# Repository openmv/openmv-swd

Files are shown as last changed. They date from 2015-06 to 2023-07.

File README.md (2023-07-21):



# openmv-swd
Serial Wire Debugger Programmer

The Serial Wire Debugger (SWD) Programmer can load firmware on up to five STM32F427/STM32F765/STM32H743 microcontrollers at the same time. The SWD Programmer is powered by the Propeller Chip. All eight cores of the Propeller Chip are used by the SWD Programmer firmware. Each SWD programming thread is run in a separate core. A master core controls the five SWD programming cores. Finally, one core provides SD card services while another core handles button debouncing and LED PWM.

If you're interested in practical code demonstrating how to load the firmware on an ST32F427/STM32F765/STM32H743 microcontroller, or generally, any ST Cortex-M4/Cortex-M7 device checkout the [SWD Code](http://github.com/openmv/openmv-swd/blob/master/module/V2/src/SWD.spin).

# openmv-swd application

* Install 7-Zip and add it to PATH.
* Install Python 2.7 and add it to PATH.
* Install Qt (to the default location).
* Install The Qt Installer Framework (to the default location).

In `/`, build the application (using the standard bare terminal):

     make.py

You'll find the installer in `module/build`.

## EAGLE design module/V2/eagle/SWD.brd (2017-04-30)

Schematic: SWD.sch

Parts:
3.3V_1,1, 3.3V_1,2, 3.3V_1,3, 3.3V_1,4, 3.3V_2,1, 3.3V_2,2, 3.3V_2,3, 3.3V_2,4, 3.3V_3,1, 3.3V_3,2, 3.3V_3,3, 3.3V_3,4, 3.3V_4,1, 3.3V_4,2, 3.3V_4,3, 3.3V_4,4, 3.3V_5,1, 3.3V_5,2, 3.3V_5,3, 3.3V_5,4: POGO_PIN_0908-4-15-20-75-14-11-0; 0908-4-15-20-75-14-11-0
C1, C2, C3, C4, C5, C6, C7, C10, C12, C13, C15, C16, C17, C18, C19, C20, C21, C22, C23, C24, C25, C27, C28, C29, C30, C31, C32, C33, C34, C35, C61, C62: 0.1uF; C0603
C8, C9: 47pF; C0603
C11, C14: 1uF; C0603
C26: 0.1uF\; C0603
C36, C37, C38, C39: 100uF; CP6.3MM
D1, D2, D3: MF-LED-0805-RED; LED0805
D4: SMBJ5.0CA; SMBJ
FRAME1: MF_FRAMEDEFAULT; MF_FRAME_DEFAULT
GND_1,1, GND_1,2, GND_1,3, GND_1,4, GND_2,1, GND_2,2, GND_2,3, GND_2,4, GND_3,1, GND_3,2, GND_3,3, GND_3,4, GND_4,1, GND_4,2, GND_4,3, GND_4,4, GND_5,1, GND_5,2, GND_5,3, GND_5,4: POGO_PIN_0908-4-15-20-75-14-11-0; 0908-4-15-20-75-14-11-0
J1: USB_TYPE-C_105450-0101; 105450-0101
J2: KLDX-0202-A; DC_PWR_JACK
L1, L2: MI0603K300R-10; L0603
R1, R2, R3, R4, R5, R6, R7, R8, R9, R14, R30, R31, R32, R33: 10K; R0603
R10: 5.1K; R0603
R11, R12: 27; R0603
R13: 4.7K; R0603
R15, R16, R17, R18, R19, R20, R21, R22, R23, R24, R25, R26, R27, R28, R29: 100; R0603
R34, R35, R36: 360; R0603
SD1: MF-MICROSD
SW1, SW2: MF-SW-TACT-6MM; TACT6MM
SWD_CLK_1,1, SWD_CLK_1,2, SWD_CLK_1,3, SWD_CLK_1,4, SWD_CLK_2,1, SWD_CLK_2,2, SWD_CLK_2,3, SWD_CLK_2,4, SWD_CLK_3,1, SWD_CLK_3,2, SWD_CLK_3,3, SWD_CLK_3,4, SWD_CLK_4,1, SWD_CLK_4,2, SWD_CLK_4,3, SWD_CLK_4,4, SWD_CLK_5,1, SWD_CLK_5,2, SWD_CLK_5,3, SWD_CLK_5,4: POGO_PIN_0908-4-15-20-75-14-11-0; 0908-4-15-20-75-14-11-0
SWD_DAT_1,1, SWD_DAT_1,2, SWD_DAT_1,3, SWD_DAT_1,4, SWD_DAT_2,1, SWD_DAT_2,2, SWD_DAT_2,3, SWD_DAT_2,4, SWD_DAT_3,1, SWD_DAT_3,2, SWD_DAT_3,3, SWD_DAT_3,4, SWD_DAT_4,1, SWD_DAT_4,2, SWD_DAT_4,3, SWD_DAT_4,4, SWD_DAT_5,1, SWD_DAT_5,2, SWD_DAT_5,3, SWD_DAT_5,4: POGO_PIN_0908-4-15-20-75-14-11-0; 0908-4-15-20-75-14-11-0
SWD_RST_1,1, SWD_RST_1,2, SWD_RST_1,3, SWD_RST_1,4, SWD_RST_2,1, SWD_RST_2,2, SWD_RST_2,3, SWD_RST_2,4, SWD_RST_3,1, SWD_RST_3,2, SWD_RST_3,3, SWD_RST_3,4, SWD_RST_4,1, SWD_RST_4,2, SWD_RST_4,3, SWD_RST_4,4, SWD_RST_5,1, SWD_RST_5,2, SWD_RST_5,3, SWD_RST_5,4: POGO_PIN_0908-4-15-20-75-14-11-0; 0908-4-15-20-75-14-11-0
U1: P8X32A-Q44; LQFP44
U2: CAT24C512WI-GT3; SOIC-8_W
U3: FT230XQ-R; FT230X_QFN-16
U4, U5, U6, U7, U8, U9, U10, U11, U12, U13, U14, U15, U16, U17, U18, U19, U20, U21, U22, U23: SN74LV4066APWR; SN74LV4066A_TSSOP-14
U24, U25, U26, U27: SSM6J507NU,LF; SSM6J507NU
U$59: MF_LOGOLOGO_TEXT; MF_LOGO_TEXT
UNIT1, UNIT2, UNIT3, UNIT4, UNIT5, UNIT6, UNIT7, UNIT8, UNIT9, UNIT10, UNIT11, UNIT12, UNIT13, UNIT14, UNIT15, UNIT16, UNIT17, UNIT18, UNIT19, UNIT20: OPENMV3
X1: ABMM-6.000MHZ-B2-T; 7MMX5MM

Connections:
3.3V: C1.P$1, C2.P$1, C3.P$1, C4.P$1, C5.P$1, C6.P$1, C7.P$1, C13.P$1, C14.P$1, C16.P$2, C17.P$2, C18.P$2, C19.P$2, C20.P$2, C21.P$2, C22.P$2, C23.P$2, C24.P$2, C25.P$2, C26.P$2, C27.P$2, C28.P$2, C29.P$2, C30.P$2, C31.P$2, C32.P$2, C33.P$2, C34.P$2, C35.P$2, C36.P$1, C37.P$1, C38.P$1, C39.P$1, C61.P$1, C62.P$1, D1.ANODE, D2.ANODE, D3.ANODE, D4.CATH (CATHODE), J2.PIN, R1.P$1, R2.P$1, R3.P$1, R4.P$1, R5.P$1, R6.P$1, R7.P$1, R8.P$1, R9.P$1, R30.P$1, R31.P$1, R32.P$1, R33.P$1, SD1.PIN4 (3.3V), U1.8 (VDD), U1.18 (VDD), U1.30 (VDD), U1.40 (VDD), U2.8 (VCC), U3.1 (VCCIO), U3.9 (RESET#), U3.10 (VCC), U4.P$14 (VCC), U5.P$14 (VCC), U6.P$14 (VCC), U7.P$14 (VCC), U8.P$14 (VCC), U9.P$14 (VCC), U10.P$14 (VCC), U11.P$14 (VCC), U12.P$14 (VCC), U13.P$14 (VCC), U14.P$14 (VCC), U15.P$14 (VCC), U16.P$14 (VCC), U17.P$14 (VCC), U18.P$14 (VCC), U19.P$14 (VCC), U20.P$14 (VCC), U21.P$14 (VCC), U22.P$14 (VCC), U23.P$14 (VCC), U24.P$1 (DRAIN), U24.P$2 (DRAIN), U24.P$5 (DRAIN), U24.P$6 (DRAIN), U24.P$8 (DRAIN), U25.P$1 (DRAIN), U25.P$2 (DRAIN), U25.P$5 (DRAIN), U25.P$6 (DRAIN), U25.P$8 (DRAIN), U26.P$1 (DRAIN), U26.P$2 (DRAIN), U26.P$5 (DRAIN), U26.P$6 (DRAIN), U26.P$8 (DRAIN), U27.P$1 (DRAIN), U27.P$2 (DRAIN), U27.P$5 (DRAIN), U27.P$6 (DRAIN), U27.P$8 (DRAIN)
3.3V_R1: 3.3V_1,1.P$1, 3.3V_2,1.P$1, 3.3V_3,1.P$1, 3.3V_4,1.P$1, 3.3V_5,1.P$1, U24.P$4 (SOURCE), U24.P$7 (SOURCE)
3.3V_R2: 3.3V_1,2.P$1, 3.3V_2,2.P$1, 3.3V_3,2.P$1, 3.3V_4,2.P$1, 3.3V_5,2.P$1, U25.P$4 (SOURCE), U25.P$7 (SOURCE)
3.3V_R3: 3.3V_1,3.P$1, 3.3V_2,3.P$1, 3.3V_3,3.P$1, 3.3V_4,3.P$1, 3.3V_5,3.P$1, U26.P$4 (SOURCE), U26.P$7 (SOURCE)
3.3V_R4: 3.3V_1,4.P$1, 3.3V_2,4.P$1, 3.3V_3,4.P$1, 3.3V_4,4.P$1, 3.3V_5,4.P$1, U27.P$4 (SOURCE), U27.P$7 (SOURCE)
3V3OUT: C12.P$1, U3.8 (3V3OUT)
!RTS: C15.P$1, U3.16 (RTS#)
CC1: J1.A5 (CC1), R10.P$1
CTRL_ROW_1: U1.44 (P3), U4.P$5 (CNTRL), U4.P$6 (CNTRL), U4.P$13 (CNTRL), U8.P$5 (CNTRL), U8.P$6 (CNTRL), U8.P$13 (CNTRL), U12.P$5 (CNTRL), U12.P$6 (CNTRL), U12.P$13 (CNTRL), U16.P$5 (CNTRL), U16.P$6 (CNTRL), U16.P$13 (CNTRL), U20.P$5 (CNTRL), U20.P$6 (CNTRL), U20.P$13 (CNTRL)
CTRL_ROW_2: U1.43 (P2), U5.P$5 (CNTRL), U5.P$6 (CNTRL), U5.P$13 (CNTRL), U9.P$5 (CNTRL), U9.P$6 (CNTRL), U9.P$13 (CNTRL), U13.P$5 (CNTRL), U13.P$6 (CNTRL), U13.P$13 (CNTRL), U17.P$5 (CNTRL), U17.P$6 (CNTRL), U17.P$13 (CNTRL), U21.P$5 (CNTRL), U21.P$6 (CNTRL), U21.P$13 (CNTRL)
CTRL_ROW_3: U1.42 (P1), U6.P$5 (CNTRL), U6.P$6 (CNTRL), U6.P$13 (CNTRL), U10.P$5 (CNTRL), U10.P$6 (CNTRL), U10.P$13 (CNTRL), U14.P$5 (CNTRL), U14.P$6 (CNTRL), U14.P$13 (CNTRL), U18.P$5 (CNTRL), U18.P$6 (CNTRL), U18.P$13 (CNTRL), U22.P$5 (CNTRL), U22.P$6 (CNTRL), U22.P$13 (CNTRL)
CTRL_ROW_4: U1.41 (P0), U7.P$5 (CNTRL), U7.P$6 (CNTRL), U7.P$13 (CNTRL), U11.P$5 (CNTRL), U11.P$6 (CNTRL), U11.P$13 (CNTRL), U15.P$5 (CNTRL), U15.P$6 (CNTRL), U15.P$13 (CNTRL), U19.P$5 (CNTRL), U19.P$6 (CNTRL), U19.P$13 (CNTRL), U23.P$5 (CNTRL), U23.P$6 (CNTRL), U23.P$13 (CNTRL)
D+: C8.P$1, J1.A6 (D+), J1.B6 (D+), R11.P$1
D-: C9.P$1, J1.A7 (D-), J1.B7 (D-), R12.P$1
GND: C1.P$2, C2.P$2, C3.P$2, C4.P$2, C5.P$2, C6.P$2, C7.P$2, C8.P$2, C9.P$2, C10.P$2, C11.P$2, C12.P$2, C13.P$2, C14.P$2, C16.P$1, C17.P$1, C18.P$1, C19.P$1, C20.P$1, C21.P$1, C22.P$1, C23.P$1, C24.P$1, C25.P$1, C26.P$1, C27.P$1, C28.P$1, C29.P$1, C30.P$1, C31.P$1, C32.P$1, C33.P$1, C34.P$1, C35.P$1, C36.P$2, C37.P$2, C38.P$2, C39.P$2, C61.P$2, C62.P$2, D4.ANODE, GND_1,1.P$1, GND_1,2.P$1, GND_1,3.P$1, GND_1,4.P$1, GND_2,1.P$1, GND_2,2.P$1, GND_2,3.P$1, GND_2,4.P$1, GND_3,1.P$1, GND_3,2.P$1, GND_3,3.P$1, GND_3,4.P$1, GND_4,1.P$1, GND_4,2.P$1, GND_4,3.P$1, GND_4,4.P$1, GND_5,1.P$1, GND_5,2.P$1, GND_5,3.P$1, GND_5,4.P$1, J1.A1 (GND), J1.A12 (GND), J1.B1 (GND), J1.B12 (GND), J2.SLEEVE1 (SLEEVE), J2.SLEEVE2 (SLEEVE_SHUNT), L2.P$2, R10.P$2, R14.P$1, R35.P$2, SD1.G0 (GND), SD1.G1 (GND), SD1.PIN6 (GND), SW1.P$3, U1.5 (VSS), U1.6 (BOE'), U1.17 (VSS), U1.27 (VSS), U1.39 (VSS), U2.1 (A0), U2.2 (A1), U2.3 (A2), U2.4 (GND), U2.7 (WP), U3.3 (GND), U3.13 (GND), U3.PAD (GND), U4.P$7 (GND), U5.P$7 (GND), U6.P$7 (GND), U7.P$7 (GND), U8.P$7 (GND), U9.P$7 (GND), U10.P$7 (GND), U11.P$7 (GND), U12.P$7 (GND), U13.P$7 (GND), U14.P$7 (GND), U15.P$7 (GND), U16.P$7 (GND), U17.P$7 (GND), U18.P$7 (GND), U19.P$7 (GND), U20.P$7 (GND), U21.P$7 (GND), U22.P$7 (GND), U23.P$7 (GND), X1.P$2 (GND), X1.P$4 (GND)
I2C_SCL: R9.P$2, U1.35 (P28), U2.6 (SCL)
I2C_SDA: R8.P$2, U1.36 (P29), U2.5 (SDA)
IRQ: R2.P$2, SD1.PIN8 (IRQ)
LED_HB: R36.P$2, U1.26 (P23)
unnamed: R16.P$1, U4.P$4 (A), U5.P$4 (A), U6.P$4 (A), U7.P$4 (A)
unnamed: R18.P$1, U8.P$1 (A), U9.P$1 (A), U10.P$1 (A), U11.P$1 (A)
unnamed: R15.P$1, U4.P$1 (A), U5.P$1 (A), U6.P$1 (A), U7.P$1 (A)
unnamed: R20.P$1, U8.P$8 (A), U9.P$8 (A), U10.P$8 (A), U11.P$8 (A)
unnamed: R19.P$1, U8.P$4 (A), U9.P$4 (A), U10.P$4 (A), U11.P$4 (A)
unnamed: R21.P$1, U12.P$1 (A), U13.P$1 (A), U14.P$1 (A), U15.P$1 (A)
unnamed: R23.P$1, U12.P$8 (A), U13.P$8 (A), U14.P$8 (A), U15.P$8 (A)
unnamed: R17.P$1, U4.P$8 (A), U5.P$8 (A), U6.P$8 (A), U7.P$8 (A)
unnamed: R22.P$1, U12.P$4 (A), U13.P$4 (A), U14.P$4 (A), U15.P$4 (A)
unnamed: R24.P$1, U16.P$1 (A), U17.P$1 (A), U18.P$1 (A), U19.P$1 (A)
unnamed: R26.P$1, U16.P$8 (A), U17.P$8 (A), U18.P$8 (A), U19.P$8 (A)
unnamed: R25.P$1, U16.P$4 (A), U17.P$4 (A), U18.P$4 (A), U19.P$4 (A)
unnamed: R27.P$1, U20.P$1 (A), U21.P$1 (A), U22.P$1 (A), U23.P$1 (A)
unnamed: R29.P$1, U20.P$8 (A), U21.P$8 (A), U22.P$8 (A), U23.P$8 (A)
unnamed: R28.P$1, U20.P$4 (A), U21.P$4 (A), U22.P$4 (A), U23.P$4 (A)
unnamed: D3.CATHODE, R36.P$1
unnamed: D2.CATHODE, R35.P$1
unnamed: C15.P$2, SW2.P$1
unnamed: D1.CATHODE, R34.P$1
PWR_1: R30.P$2, U1.22 (P19), U24.P$3 (GATE)
PWR_2: R31.P$2, U1.23 (P20), U25.P$3 (GATE)
PWR_3: R32.P$2, U1.24 (P21), U26.P$3 (GATE)
PWR_4: R33.P$2, U1.25 (P22), U27.P$3 (GATE)
RES: R1.P$2, SW1.P$2, SW2.P$4, U1.7 (RES')
RW: R7.P$2, SD1.PIN1 (RW)
RX: U1.37 (P30), U3.2 (RXD)
SD_CLK: R4.P$2, SD1.PIN5 (SCLK), U1.32 (P25)
SD_CS: R6.P$2, SD1.PIN2 (CS), U1.34 (P27)
SD_DI: R5.P$2, SD1.PIN3 (DI), U1.33 (P26)
SD_DO: R3.P$2, SD1.PIN7 (D0), U1.31 (P24)
SHLD: J1.S_T1 (SHLD), J1.S_T2 (SHLD), J1.S_T3 (SHLD), J1.S_T4 (SHLD), L2.P$1
SWD_CLK_1: R15.P$2, U1.1 (P4)
SWD_CLK_1,1: SWD_CLK_1,1.P$1, U4.P$2 (B)
SWD_CLK_1,2: SWD_CLK_1,2.P$1, U5.P$2 (B)
SWD_CLK_1,3: SWD_CLK_1,3.P$1, U6.P$2 (B)
SWD_CLK_1,4: SWD_CLK_1,4.P$1, U7.P$2 (B)
SWD_CLK_2: R18.P$2, U1.4 (P7)
SWD_CLK_2,1: SWD_CLK_2,1.P$1, U8.P$2 (B)
SWD_CLK_2,2: SWD_CLK_2,2.P$1, U9.P$2 (B)
SWD_CLK_2,3: SWD_CLK_2,3.P$1, U10.P$2 (B)
SWD_CLK_2,4: SWD_CLK_2,4.P$1, U11.P$2 (B)
SWD_CLK_3: R21.P$2, U1.11 (P10)
SWD_CLK_3,1: SWD_CLK_3,1.P$1, U12.P$2 (B)
SWD_CLK_3,2: SWD_CLK_3,2.P$1, U13.P$2 (B)
SWD_CLK_3,3: SWD_CLK_3,3.P$1, U14.P$2 (B)
SWD_CLK_3,4: SWD_CLK_3,4.P$1, U15.P$2 (B)
SWD_CLK_4: R24.P$2, U1.14 (P13)
SWD_CLK_4,1: SWD_CLK_4,1.P$1, U16.P$2 (B)
SWD_CLK_4,2: SWD_CLK_4,2.P$1, U17.P$2 (B)
SWD_CLK_4,3: SWD_CLK_4,3.P$1, U18.P$2 (B)
SWD_CLK_4,4: SWD_CLK_4,4.P$1, U19.P$2 (B)
SWD_CLK_5: R27.P$2, U1.19 (P16)
SWD_CLK_5,1: SWD_CLK_5,1.P$1, U20.P$2 (B)
SWD_CLK_5,2: SWD_CLK_5,2.P$1, U21.P$2 (B)
SWD_CLK_5,3: SWD_CLK_5,3.P$1, U22.P$2 (B)
SWD_CLK_5,4: SWD_CLK_5,4.P$1, U23.P$2 (B)
SWD_DAT_1: R16.P$2, U1.2 (P5)
SWD_DAT_1,1: SWD_DAT_1,1.P$1, U4.P$3 (B)
SWD_DAT_1,2: SWD_DAT_1,2.P$1, U5.P$3 (B)
SWD_DAT_1,3: SWD_DAT_1,3.P$1, U6.P$3 (B)
SWD_DAT_1,4: SWD_DAT_1,4.P$1, U7.P$3 (B)
SWD_DAT_2: R19.P$2, U1.9 (P8)
SWD_DAT_2,1: SWD_DAT_2,1.P$1, U8.P$3 (B)
SWD_DAT_2,2: SWD_DAT_2,2.P$1, U9.P$3 (B)
SWD_DAT_2,3: SWD_DAT_2,3.P$1, U10.P$3 (B)
SWD_DAT_2,4: SWD_DAT_2,4.P$1, U11.P$3 (B)
SWD_DAT_3: R22.P$2, U1.12 (P11)
SWD_DAT_3,1: SWD_DAT_3,1.P$1, U12.P$3 (B)
SWD_DAT_3,2: SWD_DAT_3,2.P$1, U13.P$3 (B)
SWD_DAT_3,3: SWD_DAT_3,3.P$1, U14.P$3 (B)
SWD_DAT_3,4: SWD_DAT_3,4.P$1, U15.P$3 (B)
SWD_DAT_4: R25.P$2, U1.15 (P14)
SWD_DAT_4,1: SWD_DAT_4,1.P$1, U16.P$3 (B)
SWD_DAT_4,2: SWD_DAT_4,2.P$1, U17.P$3 (B)
SWD_DAT_4,3: SWD_DAT_4,3.P$1, U18.P$3 (B)
SWD_DAT_4,4: SWD_DAT_4,4.P$1, U19.P$3 (B)
SWD_DAT_5: R28.P$2, U1.20 (P17)
SWD_DAT_5,1: SWD_DAT_5,1.P$1, U20.P$3 (B)
SWD_DAT_5,2: SWD_DAT_5,2.P$1, U21.P$3 (B)
SWD_DAT_5,3: SWD_DAT_5,3.P$1, U22.P$3 (B)
SWD_DAT_5,4: SWD_DAT_5,4.P$1, U23.P$3 (B)
SWD_RST_1: R17.P$2, U1.3 (P6)
SWD_RST_1,1: SWD_RST_1,1.P$1, U4.P$9 (B)
SWD_RST_1,2: SWD_RST_1,2.P$1, U5.P$9 (B)
SWD_RST_1,3: SWD_RST_1,3.P$1, U6.P$9 (B)
SWD_RST_1,4: SWD_RST_1,4.P$1, U7.P$9 (B)
SWD_RST_2: R20.P$2, U1.10 (P9)
SWD_RST_2,1: SWD_RST_2,1.P$1, U8.P$9 (B)
SWD_RST_2,2: SWD_RST_2,2.P$1, U9.P$9 (B)
SWD_RST_2,3: SWD_RST_2,3.P$1, U10.P$9 (B)
SWD_RST_2,4: SWD_RST_2,4.P$1, U11.P$9 (B)
SWD_RST_3: R23.P$2, U1.13 (P12)
SWD_RST_3,1: SWD_RST_3,1.P$1, U12.P$9 (B)
SWD_RST_3,2: SWD_RST_3,2.P$1, U13.P$9 (B)
SWD_RST_3,3: SWD_RST_3,3.P$1, U14.P$9 (B)
SWD_RST_3,4: SWD_RST_3,4.P$1, U15.P$9 (B)
SWD_RST_4: R26.P$2, U1.16 (P15)
SWD_RST_4,1: SWD_RST_4,1.P$1, U16.P$9 (B)
SWD_RST_4,2: SWD_RST_4,2.P$1, U17.P$9 (B)
SWD_RST_4,3: SWD_RST_4,3.P$1, U18.P$9 (B)
SWD_RST_4,4: SWD_RST_4,4.P$1, U19.P$9 (B)
SWD_RST_5: R29.P$2, U1.21 (P18)
SWD_RST_5,1: SWD_RST_5,1.P$1, U20.P$9 (B)
SWD_RST_5,2: SWD_RST_5,2.P$1, U21.P$9 (B)
SWD_RST_5,3: SWD_RST_5,3.P$1, U22.P$9 (B)
SWD_RST_5,4: SWD_RST_5,4.P$1, U23.P$9 (B)
TX: U1.38 (P31), U3.15 (TXD)
TXRX_LED: R34.P$2, U3.5 (CBUS2)
USBDM: R12.P$2, U3.7 (USBDM)
USBDP: R11.P$2, U3.6 (USBDP)
VBUS_SENSE: R13.P$1, R14.P$2, U3.12 (CBUS0)
V_USB: J1.A4 (VBUS), J1.A9 (VBUS), J1.B4 (VBUS), J1.B9 (VBUS), L1.P$1
V_USB_SENSE: C10.P$1, C11.P$1, L1.P$2, R13.P$2
X0: U1.29 (X0), X1.P$3 (X1)
X1: U1.28 (X1), X1.P$1 (X0)

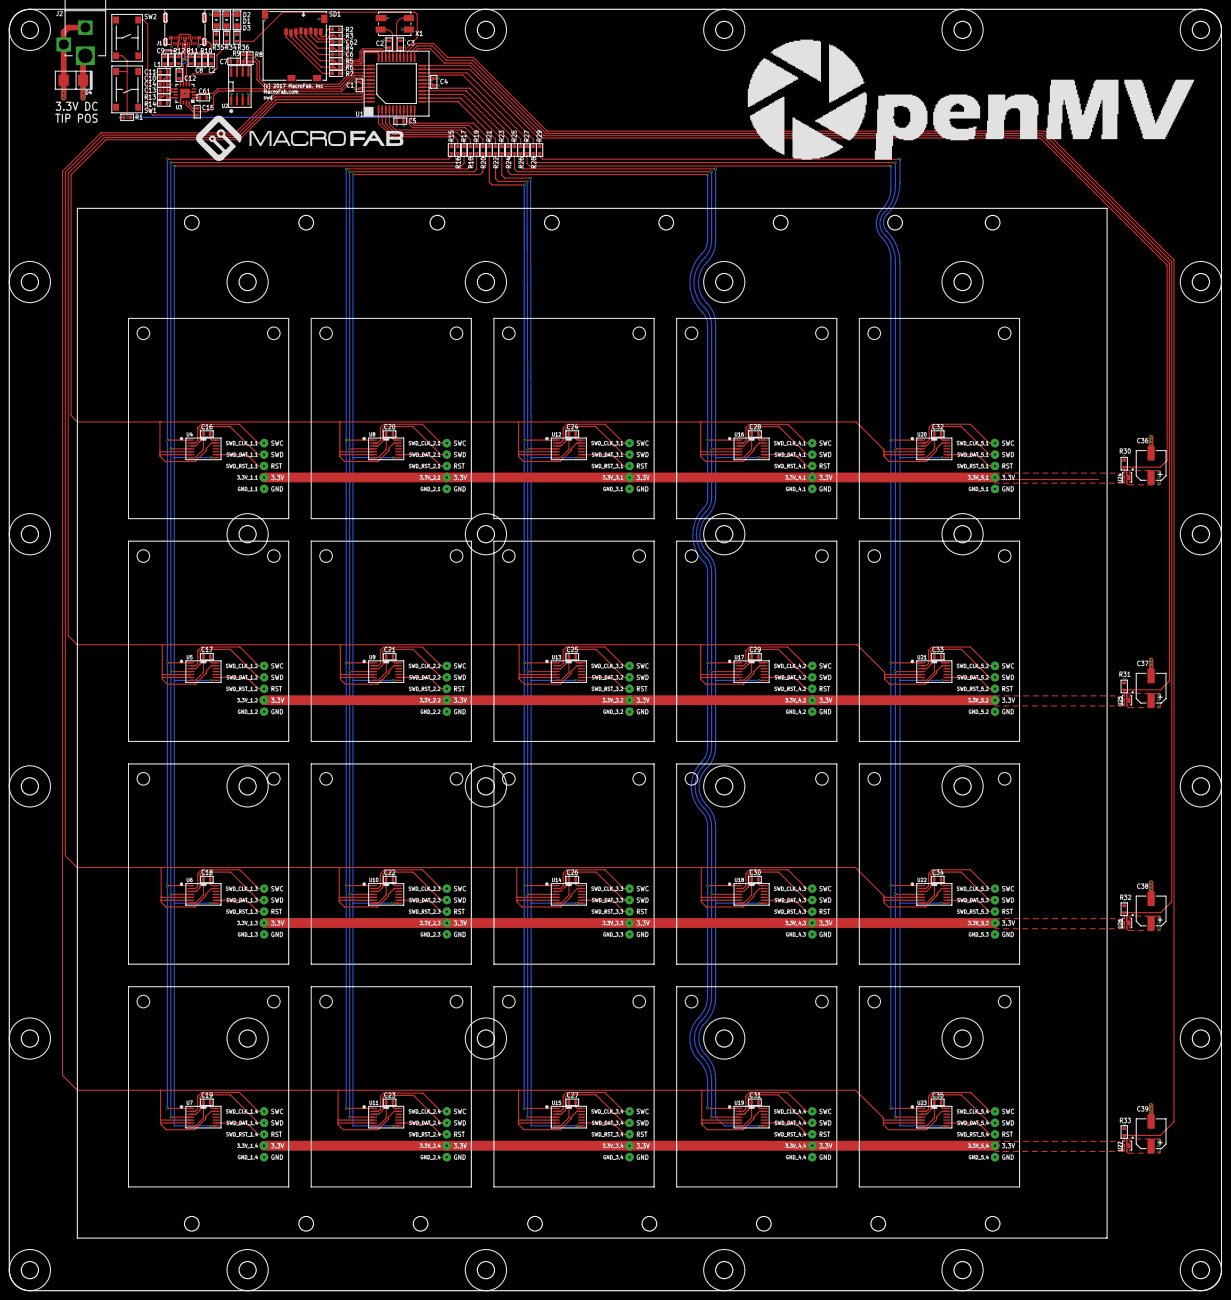
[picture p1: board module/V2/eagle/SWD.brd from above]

Board: 4 copper layers, 269.1 x 284.5 mm, 273 parts (0 on the bottom side), 134 nets.

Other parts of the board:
U$24, U$25, U$26, U$27, U$28, U$29, U$30, U$31, U$32, U$33, U$34, U$35, U$36, U$37, U$38, U$39, U$40, U$41, U$42, U$43, U$44, U$45, U$46, U$47, U$48, U$49, U$50, U$51, U$52, U$53, U$54, U$55, U$56, U$57, U$58: MOUNT_HOLE_150MIL

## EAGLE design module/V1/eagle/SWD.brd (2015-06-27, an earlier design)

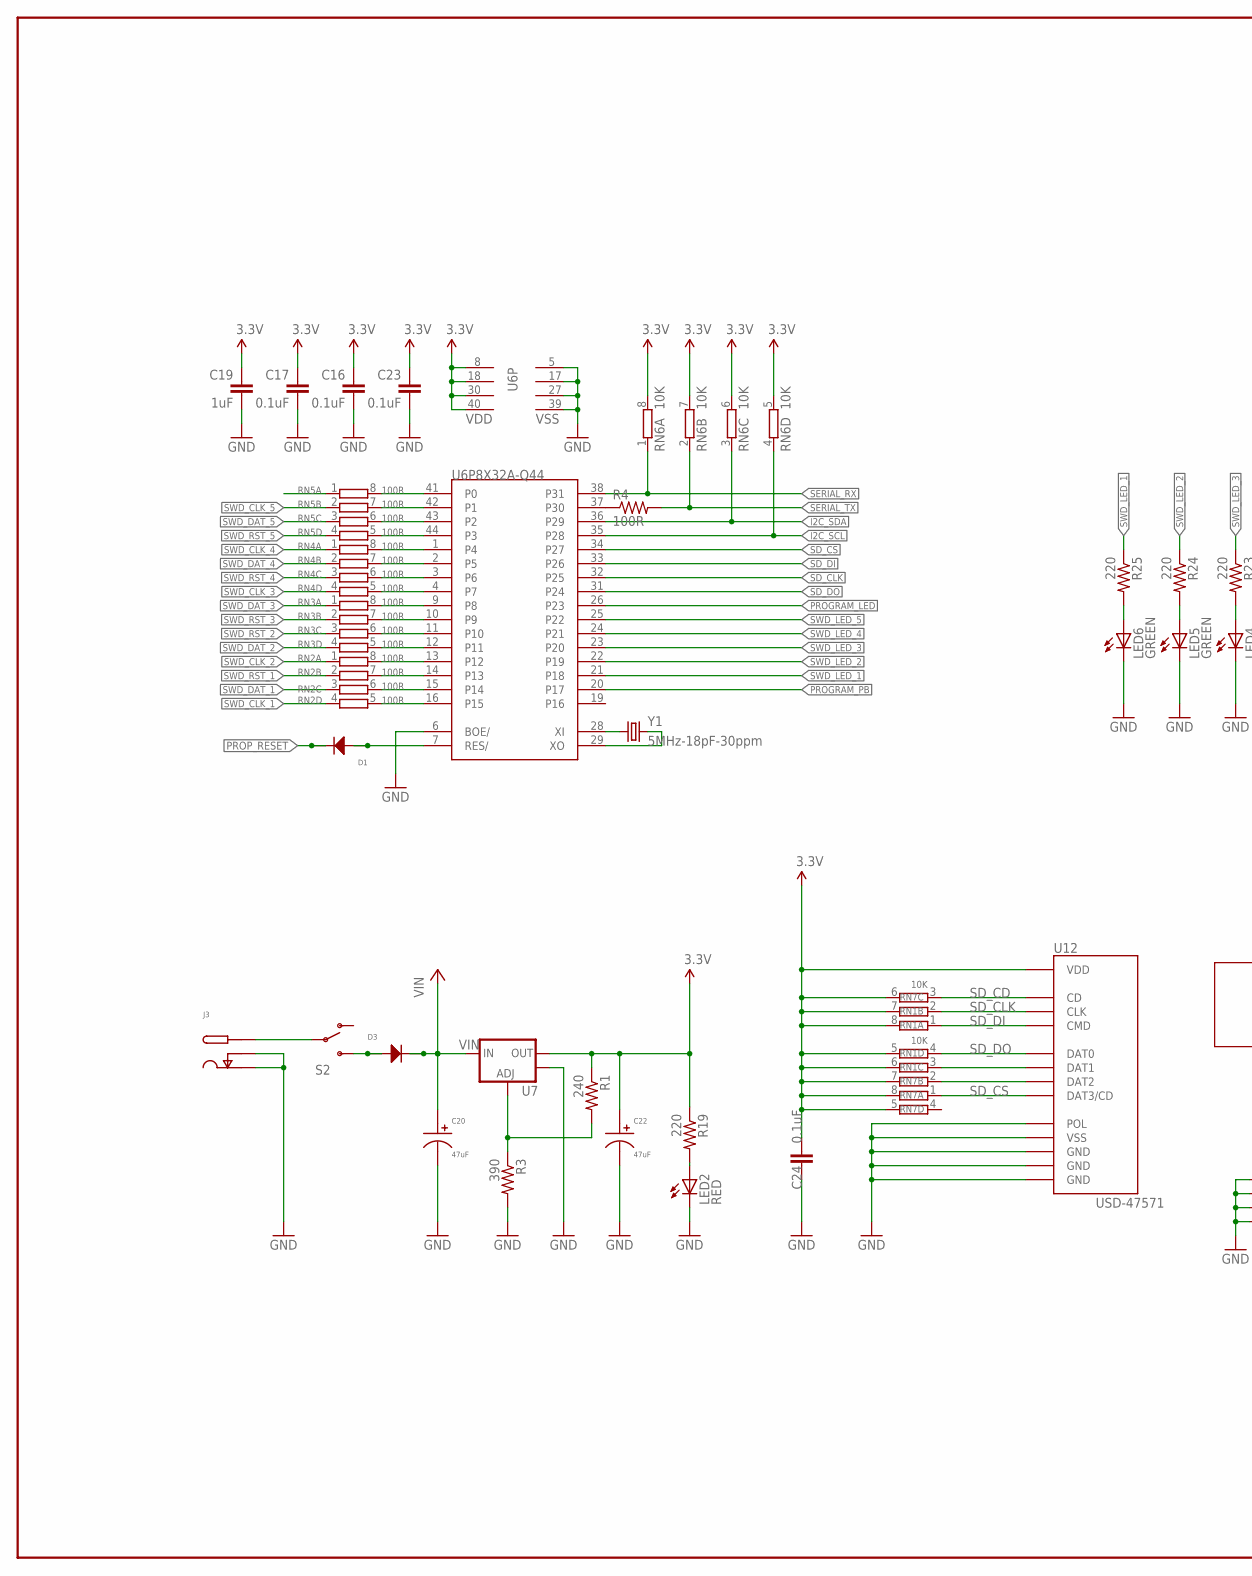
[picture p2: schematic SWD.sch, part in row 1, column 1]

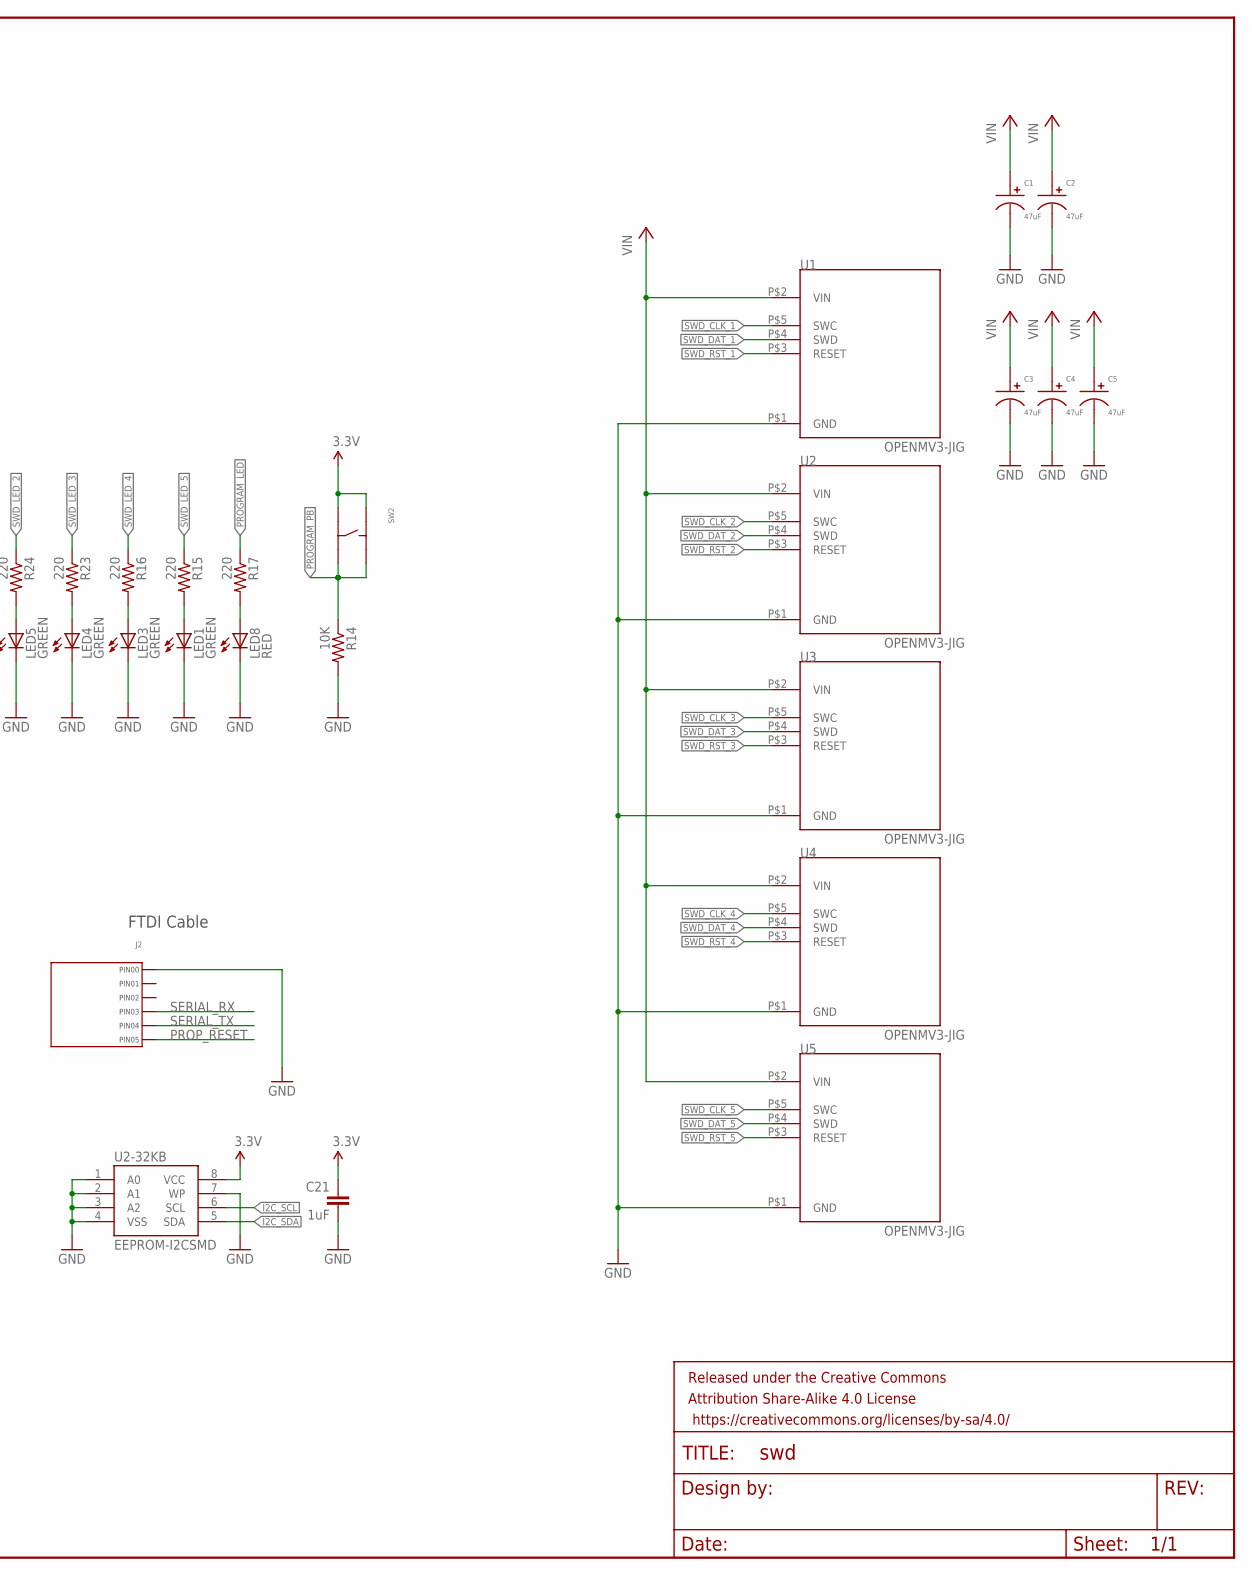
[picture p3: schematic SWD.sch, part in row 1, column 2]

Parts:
C1, C2, C3, C4, C5: 47uF; CP6.3MM; TOLERANCE N/A; MFG# N/A
C16, C17, C23, C24: 0.1uF; 0603-CAP
C19, C21: 1uF; 0603-CAP
C20, C22: 47uF; CP6.3MM
D1: DIODE_SOD-123; SOD-123
D3: DIODE_SMA; SMA
FRAME1: FRAME-LEDGER; CREATIVE_COMMONS
J2: HEADER_01X06_PTH_2.54MM; PTH_2.54MM_01X06
J3: DC_PWR_JACK_2.5MM_RIGHT; DC_PWR_JACK
LED1, LED3, LED4, LED5, LED6: GREEN; LED-0603
LED2, LED8: RED; LED-0603
R1: 240; 0603-RES
R3: 390; 0603-RES
R4: 100R; 0603-RES
R14: 10K; 0603-RES
R15, R16, R17, R19, R23, R24, R25: 220; 0603-RES
RN1, RN6, RN7: 10K; EXBV8V
RN2, RN3, RN4, RN5: 100R; EXBV8V
S2: SWITCH-SPSTPTH; SWITCH-SPDT
SW2: TACT_6MM; TACT6MM
U1, U2, U3, U4, U5: OPENMV3-JIG
U2-32KB: EEPROM-I2CSMD; SO08
U6: P8X32A-Q44
U7: V_REG_LM1117SOT223; SOT223
U12: USD-47571
Y1: 5MHz-18pF-30ppm; HC49UP

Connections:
3.3V: C16.1, C17.1, C19.1, C21.1, C22.P$1, C23.1, C24.1, R1.1, R19.1, RN1.5 (2), RN1.6 (2), RN1.7 (2), RN1.8 (2), RN6.5 (2), RN6.6 (2), RN6.7 (2), RN6.8 (2), RN7.5 (2), RN7.6 (2), RN7.7 (2), RN7.8 (2), SW2.P$1, SW2.P$3, U2-32KB.8 (VCC), U6.8 (VDD), U6.18 (VDD), U6.30 (VDD), U6.40 (VDD), U7.2 (OUT), U12.P$4 (VDD)
GND: C1.P$2, C2.P$2, C3.P$2, C4.P$2, C5.P$2, C16.2, C17.2, C19.2, C20.P$2, C21.2, C22.P$2, C23.2, C24.2, J2.P$1 (PIN0), J3.SLEEVE1 (SLEEVE), J3.SLEEVE2 (SLEEVE_SHUNT), LED1.C, LED2.C, LED3.C, LED4.C, LED5.C, LED6.C, LED8.C, R3.2, R14.2, U1.P$1 (GND), U2.P$1 (GND), U2-32KB.1 (A0), U2-32KB.2 (A1), U2-32KB.3 (A2), U2-32KB.4 (VSS), U2-32KB.7 (WP), U3.P$1 (GND), U4.P$1 (GND), U5.P$1 (GND), U6.5 (VSS), U6.6 (BOE/), U6.17 (VSS), U6.27 (VSS), U6.39 (VSS), U7.4 (OUT), U12.G$1 (GND), U12.G$2 (GND), U12.G$3 (GND), U12.G$4 (POL), U12.P$6 (VSS)
I2C_SCL: RN6.4 (1), U2-32KB.6 (SCL), U6.35 (P28)
I2C_SDA: RN6.3 (1), U2-32KB.5 (SDA), U6.36 (P29)
unnamed: R4.1, U6.37 (P30)
unnamed: D3.ANODE, S2.3 (S)
unnamed: U6.28 (XI), Y1.1
unnamed: U6.29 (XO), Y1.2
unnamed: LED2.A, R19.2
unnamed: D1.ANODE, U6.7 (RES/)
unnamed: J3.PIN, S2.2
unnamed: RN1.3 (1), U12.P$8 (DAT1)
unnamed: RN7.2 (1), U12.P$1 (DAT2)
unnamed: LED6.A, R25.2
unnamed: LED5.A, R24.2
unnamed: LED4.A, R23.2
unnamed: LED3.A, R16.2
unnamed: LED1.A, R15.2
unnamed: LED8.A, R17.2
unnamed: RN2.8 (2), U6.13 (P12)
unnamed: RN2.7 (2), U6.14 (P13)
unnamed: RN2.6 (2), U6.15 (P14)
unnamed: RN2.5 (2), U6.16 (P15)
unnamed: RN3.5 (2), U6.12 (P11)
unnamed: RN3.6 (2), U6.11 (P10)
unnamed: RN3.7 (2), U6.10 (P9)
unnamed: RN3.8 (2), U6.9 (P8)
unnamed: R1.2, R3.1, U7.1 (ADJ)
unnamed: RN5.6 (2), U6.43 (P2)
unnamed: RN5.7 (2), U6.42 (P1)
unnamed: RN5.8 (2), U6.41 (P0)
unnamed: RN5.5 (2), U6.44 (P3)
unnamed: RN4.8 (2), U6.1 (P4)
unnamed: RN4.7 (2), U6.2 (P5)
unnamed: RN4.6 (2), U6.3 (P6)
unnamed: RN4.5 (2), U6.4 (P7)
PROGRAM_LED: R17.1, U6.26 (P23)
PROGRAM_PB: R14.1, SW2.P$2, SW2.P$4, U6.20 (P17)
PROP_RESET: D1.CATHODE, J2.P$6 (PIN5)
SD_CD: RN7.3 (1), U12.G$5 (CD)
SD_CLK: RN1.2 (1), U6.32 (P25), U12.P$5 (CLK)
SD_CS: RN7.1, U6.34 (P27), U12.P$2 (DAT3/CD)
SD_DI: RN1.1, U6.33 (P26), U12.P$3 (CMD)
SD_DO: RN1.4 (1), U6.31 (P24), U12.P$7 (DAT0)
SERIAL_RX: J2.P$4 (PIN3), RN6.1, U6.38 (P31)
SERIAL_TX: J2.P$5 (PIN4), R4.2, RN6.2 (1)
SWD_CLK_1: RN2.4 (1), U1.P$5 (SWC)
SWD_CLK_2: RN2.1, U2.P$5 (SWC)
SWD_CLK_3: RN4.4 (1), U3.P$5 (SWC)
SWD_CLK_4: RN4.1, U4.P$5 (SWC)
SWD_CLK_5: RN5.2 (1), U5.P$5 (SWC)
SWD_DAT_1: RN2.3 (1), U1.P$4 (SWD)
SWD_DAT_2: RN3.4 (1), U2.P$4 (SWD)
SWD_DAT_3: RN3.1, U3.P$4 (SWD)
SWD_DAT_4: RN4.2 (1), U4.P$4 (SWD)
SWD_DAT_5: RN5.3 (1), U5.P$4 (SWD)
SWD_LED_1: R25.1, U6.21 (P18)
SWD_LED_2: R24.1, U6.22 (P19)
SWD_LED_3: R23.1, U6.23 (P20)
SWD_LED_4: R16.1, U6.24 (P21)
SWD_LED_5: R15.1, U6.25 (P22)
SWD_RST_1: RN2.2 (1), U1.P$3 (RESET)
SWD_RST_2: RN3.3 (1), U2.P$3 (RESET)
SWD_RST_3: RN3.2 (1), U3.P$3 (RESET)
SWD_RST_4: RN4.3 (1), U4.P$3 (RESET)
SWD_RST_5: RN5.4 (1), U5.P$3 (RESET)
VIN: C1.P$1, C2.P$1, C3.P$1, C4.P$1, C5.P$1, C20.P$1, D3.CATHODE, U1.P$2 (VIN), U2.P$2 (VIN), U3.P$2 (VIN), U4.P$2 (VIN), U5.P$2 (VIN), U7.3 (IN)

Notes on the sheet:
FTDI Cable

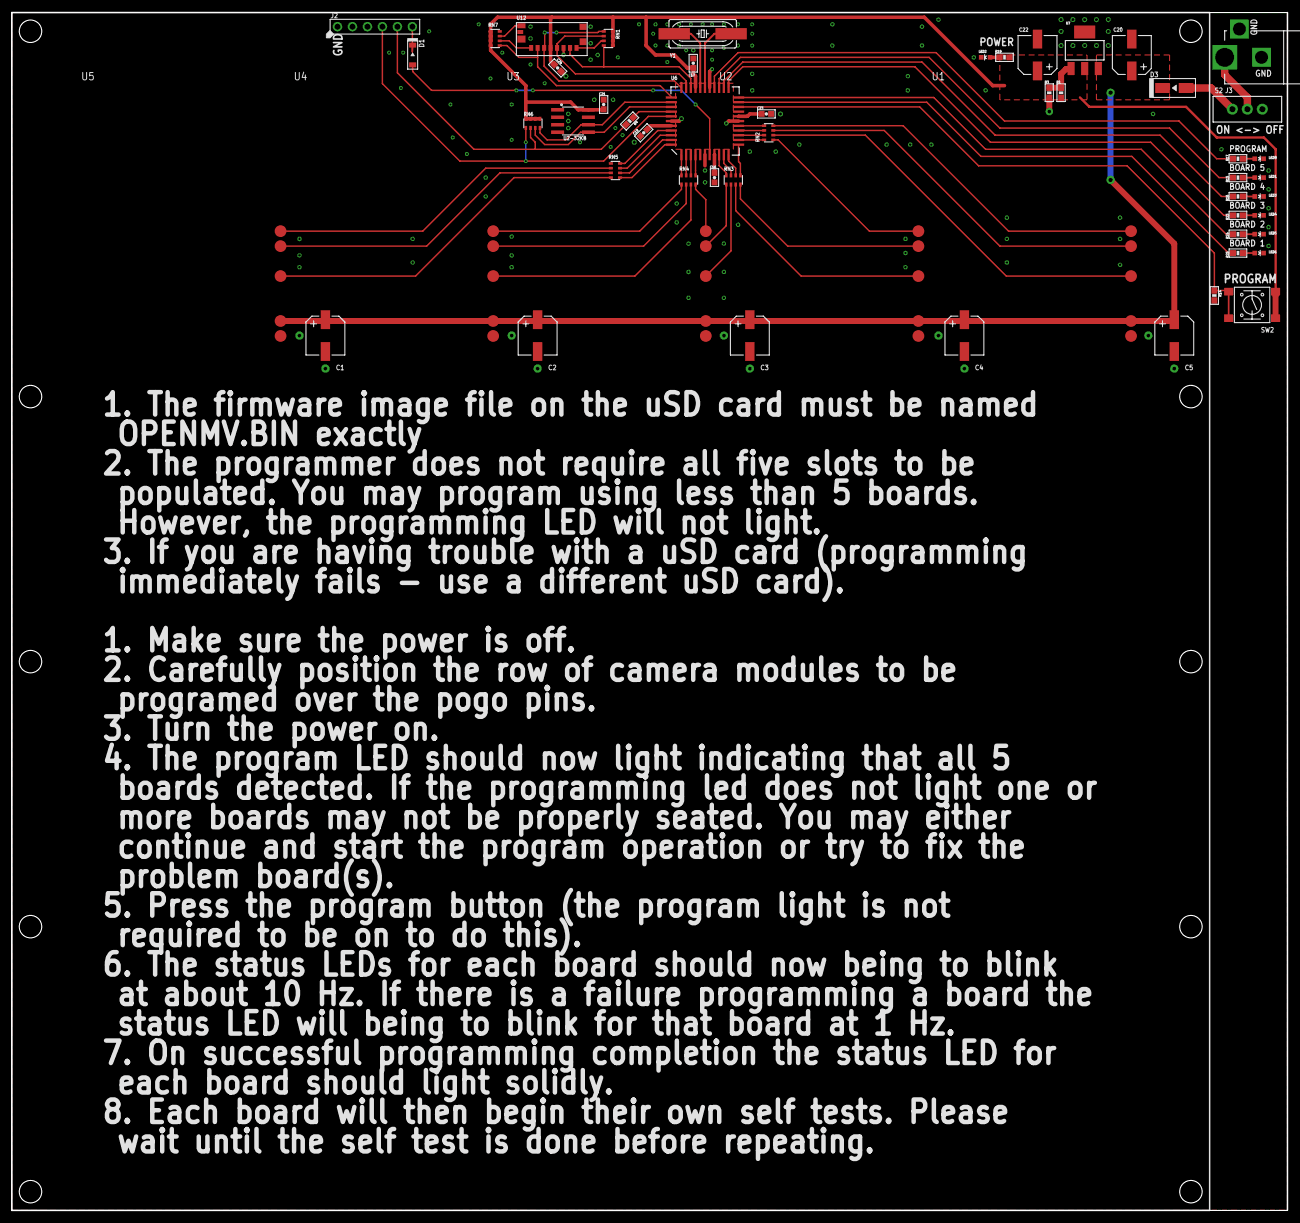
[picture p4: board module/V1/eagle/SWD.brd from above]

Board: 2 copper layers, 216.4 x 203.2 mm, 55 parts (0 on the bottom side), 67 nets.

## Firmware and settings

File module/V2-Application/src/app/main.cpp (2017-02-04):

/****************************************************************************
**
** Copyright (C) 2016 The Qt Company Ltd.
** Contact: https://www.qt.io/licensing/
**
** Commercial License Usage
** Licensees holding valid commercial Qt licenses may use this file in
** accordance with the commercial license agreement provided with the
** Software or, alternatively, in accordance with the terms contained in
** a written agreement between you and The Qt Company. For licensing terms
** and conditions see https://www.qt.io/terms-conditions. For further
** information use the contact form at https://www.qt.io/contact-us.
**
** GNU General Public License Usage
** Alternatively, this file may be used under the terms of the GNU
** General Public License version 3 as published by the Free Software
** Foundation with exceptions as appearing in the file LICENSE.GPL3-EXCEPT
** included in the packaging of this file. Please review the following
** information to ensure the GNU General Public License requirements will
** be met: https://www.gnu.org/licenses/gpl-3.0.html.
**
****************************************************************************/

#include <app/app_version.h>
#include <qtsingleapplication.h>

#include <QtCore>
#include <QtWidgets>
#include <QtNetwork>

#include "openmvswd.h"

static const char *setHighDpiEnvironmentVariable()
{
    const char* envVarName = 0;
    static const char ENV_VAR_QT_DEVICE_PIXEL_RATIO[] = "QT_DEVICE_PIXEL_RATIO";
#if (QT_VERSION < QT_VERSION_CHECK(5, 6, 0))
    if (Utils::HostOsInfo().isWindowsHost()
            && !qEnvironmentVariableIsSet(ENV_VAR_QT_DEVICE_PIXEL_RATIO)) {
        envVarName = ENV_VAR_QT_DEVICE_PIXEL_RATIO;
        qputenv(envVarName, "auto");
    }
#else
    #if defined(Q_OS_WIN)
        if(!qEnvironmentVariableIsSet(ENV_VAR_QT_DEVICE_PIXEL_RATIO) // legacy in 5.6, but still functional
                && !qEnvironmentVariableIsSet("QT_AUTO_SCREEN_SCALE_FACTOR")
                && !qEnvironmentVariableIsSet("QT_SCALE_FACTOR")
                && !qEnvironmentVariableIsSet("QT_SCREEN_SCALE_FACTORS")) {
            QCoreApplication::setAttribute(Qt::AA_EnableHighDpiScaling);
        }
    #endif
#endif // < Qt 5.6
    return envVarName;
}

int main(int argc, char **argv)
{
    const char *highDpiEnvironmentVariable = setHighDpiEnvironmentVariable();

#ifdef Q_OS_MAC
    // increase the number of file that can be opened.
    struct rlimit rl;
    getrlimit(RLIMIT_NOFILE, &rl);

    rl.rlim_cur = qMin((rlim_t)OPEN_MAX, rl.rlim_max);
    setrlimit(RLIMIT_NOFILE, &rl);
#endif

    SharedTools::QtSingleApplication app(QLatin1String("OpenMV SWD"), argc, argv);

    if (app.sendMessage(QLatin1String("Hello World!"))) {
        return 0;
    }

    if (highDpiEnvironmentVariable)
        qunsetenv(highDpiEnvironmentVariable);

#if defined(Q_OS_WIN)
    if(!qFuzzyCompare(qApp->devicePixelRatio(), 1.0)
            && QApplication::style()->objectName().startsWith(
                QLatin1String("windows"), Qt::CaseInsensitive)) {
        QApplication::setStyle(QLatin1String("fusion"));
    }
#endif

    const int threadCount = QThreadPool::globalInstance()->maxThreadCount();
    QThreadPool::globalInstance()->setMaxThreadCount(qMax(4, 2 * threadCount));

    app.setAttribute(Qt::AA_UseHighDpiPixmaps);

    // Make sure we honor the system's proxy settings
    QNetworkProxyFactory::setUseSystemConfiguration(true);

    OpenMVSWD *w = new OpenMVSWD();
    app.setActivationWindow(w);

    QTimer::singleShot(1, w, [w] {w->show();});
    return app.exec();
}

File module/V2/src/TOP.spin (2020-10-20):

' by: Kwabena W. Agyeman - kwagyeman@openmv.io

con

  _CLKFREQ = 96_000_000
  _CLKMODE = XTAL1 + PLL16X

  NUM_SWD = 5
  NUM_SEL = 4

  HEART_BEAT_LED = 23

  SD_DO_PIN = 24
  SD_CLK_PIN = 25
  SD_DI_PIN = 26
  SD_CS_PIN = 27
  SD_WP_PIN = -1
  SD_CD_PIN = -1

  TX_PIN = 30
  RX_PIN = 31

  BAUD_RATE = 115200

var

  long hb_cnt, hb_state, command_buf, command_state

dat

  swd_io_pin byte 5, 8, 11, 14, 17
  swd_clk_pin byte 4, 7, 10, 13, 16
  swd_res_pin byte 6, 9, 12, 15, 18

  swd_sel_pin byte 3, 2, 1, 0
  swd_pwr_pin byte 19, 20, 21, 22

  m4_firmware_file_name byte "OPENMV2/OPENMV.BIN", 0 ' 8.3 file name
  m7_firmware_file_name byte "OPENMV3/OPENMV.BIN", 0 ' 8.3 file name
  h7_firmware_file_name byte "OPENMV4/OPENMV.BIN", 0 ' 8.3 file name

obj

  com : "Full-Duplex_COMEngine.spin"
  fat[NUM_SWD] : "SD-MMC_FATEngine.spin"
  swd[NUM_SWD] : "SWD.spin"

con

  #0, SWD_IDLE, SWD_BEGIN_INITING, SWD_BEGIN_PROGRAMMING, SWD_PROGRAMMING, SWD_VERIFYING, SWD_FINISHED, SWD_FATAL_ERROR

var

  long board_state[NUM_SWD], remaining_blocks[NUM_SWD], debounce_cnt[NUM_SWD], debounce_shift[NUM_SWD], debounce_state[NUM_SWD], null

pub main | i, x, r

  com.COMEngineStart(RX_PIN, TX_PIN, BAUD_RATE)
  fat.FATEngineStart(SD_DO_PIN, SD_CLK_PIN, SD_DI_PIN, SD_CS_PIN, SD_WP_PIN, SD_CD_PIN, -1, -1, -1)

  hb_cnt := cnt

  repeat i from 0 to constant(NUM_SWD - 1)
    debounce_cnt[i] := cnt

  dira[HEART_BEAT_LED] := 1

  repeat i from 0 to constant(NUM_SEL - 1)
    outa[swd_pwr_pin[i]] := 1
    dira[swd_pwr_pin[i]] := 1
    dira[swd_sel_pin[i]] := 1

  repeat
    x := 0

    repeat while com.receivedNumber
      command_buf := (command_buf << 8) | com.readByte
      case command_buf

        $53_57_44_30: ' Program SWD 0
          if debounce_reset(0)
            x := constant(0 + 1)
          else
            com.writeString(string("SWD0 [Not Ready] 0%", com#Carriage_Return, com#Line_Feed))
          quit

        $53_57_44_31: ' Program SWD 1
          if debounce_reset(1)
            x := constant(1 + 1)
          else
            com.writeString(string("SWD1 [Not Ready] 0%", com#Carriage_Return, com#Line_Feed))
          quit

        $53_57_44_32: ' Program SWD 2
          if debounce_reset(2)
            x := constant(2 + 1)
          else
            com.writeString(string("SWD2 [Not Ready] 0%", com#Carriage_Return, com#Line_Feed))
          quit

        $53_57_44_33: ' Program SWD 3
          if debounce_reset(3)
            x := constant(3 + 1)
          else
            com.writeString(string("SWD3 [Not Ready] 0%", com#Carriage_Return, com#Line_Feed))
          quit

        $53_57_44_34: ' Program SWD 4
          if debounce_reset(4)
            x := constant(4 + 1)
          else
            com.writeString(string("SWD4 [Not Ready] 0%", com#Carriage_Return, com#Line_Feed))
          quit

        $53_57_44_35: ' Activate row 0
          kill_port
          if command_state~ <> constant(0 + 1)
            command_state := constant(0 + 1)
            outa[swd_sel_pin[0]] := 1
            outa[swd_pwr_pin[0]] := 0
            debounce_reset_wait
            com.writeString(string("ROW0 On", com#Carriage_Return, com#Line_Feed))
          quit

        $53_57_44_36: ' Activate row 1
          kill_port
          if command_state~ <> constant(1 + 1)
            command_state := constant(1 + 1)
            outa[swd_sel_pin[1]] := 1
            outa[swd_pwr_pin[1]] := 0
            debounce_reset_wait
            com.writeString(string("ROW1 On", com#Carriage_Return, com#Line_Feed))
          quit

        $53_57_44_37: ' Activate row 2
          kill_port
          if command_state~ <> constant(2 + 1)
            command_state := constant(2 + 1)
            outa[swd_sel_pin[2]] := 1
            outa[swd_pwr_pin[2]] := 0
            debounce_reset_wait
            com.writeString(string("ROW2 On", com#Carriage_Return, com#Line_Feed))
          quit

        $53_57_44_38: ' Activate row 3
          kill_port
          if command_state~ <> constant(3 + 1)
            command_state := constant(3 + 1)
            outa[swd_sel_pin[3]] := 1
            outa[swd_pwr_pin[3]] := 0
            debounce_reset_wait
            com.writeString(string("ROW3 On", com#Carriage_Return, com#Line_Feed))
          quit

        $53_57_44_39: ' Ping
          com.writeString(string("Hello World - v3.3.0", com#Carriage_Return, com#Line_Feed))
          quit

    repeat i from 0 to constant(NUM_SWD - 1)
      debounce_reset(i)
      case board_state[i]

        SWD_IDLE:
          if x == (i + 1)
            board_state[i] := SWD_BEGIN_INITING

        SWD_BEGIN_INITING:
          r := \begin_initing(i)

          if r
            board_state[i] := SWD_FATAL_ERROR

        SWD_BEGIN_PROGRAMMING:
          r := \begin_programming(i)

          if r
            board_state[i] := SWD_FATAL_ERROR

        SWD_PROGRAMMING:
          r := \programming(i)

          if r
            board_state[i] := SWD_FATAL_ERROR
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

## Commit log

2015-06-15 Add SWD jig
    [SWD.brd, SWD.sch]
2015-06-25 * Update jig (see details)
    * Make SWD resistors 100 ohms (RN5-RN2)
    * Remove D1 (not really needed).
    * Add propeller reset circuit.
    * Change all pull-up resistors to 10K.
    * Add more silkscreen labels (power switch, power LED, 5V input).
    * Use different colors for the power LED, program LED, and board LEDs.
    * Add jig instructions to the silk screen.
    * Move power LED to be visible.
    * Remove FT231x and use FTDI cable header.
    * Terminate propeller TX.
    [SWD.brd, SWD.sch]
2015-06-27 Replace common parts with MF parts
    [SWD.brd, SWD.sch]
2017-01-30 Update SWD
    [SWD.brd, SWD.sch]
2017-04-30 Fixed wire errors
    [SWD.brd, SWD.sch]
2017-05-04 Added enable buttons

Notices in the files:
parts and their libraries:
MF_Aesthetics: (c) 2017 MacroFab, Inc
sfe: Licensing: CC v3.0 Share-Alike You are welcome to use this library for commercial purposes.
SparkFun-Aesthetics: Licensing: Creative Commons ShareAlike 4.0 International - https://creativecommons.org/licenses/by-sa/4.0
